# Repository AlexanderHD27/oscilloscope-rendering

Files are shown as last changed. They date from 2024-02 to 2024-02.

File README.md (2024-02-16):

# Oscilloscope Drawing

A device that draws on an oscilloscope.

## Introduction
Drawing on analog oscilloscope is almost a classic in the electronics/microcontroller community now.
This is done by setting the scope to XY-Mode and then controlling the X/Y-deflection of the electron-beam. My Scope has no Z-Channel. I cannot control the intensity of beam (or switches off) by voltage yet

This Project is my shot at this. I use custom hardware (build on perf-board) to archive this goal. I have build
a 2-Channel 16bit DAC with an refresh rate of around 1 MSample per second. Further more a usb-interface + driver shall be developed.

<p float="left">
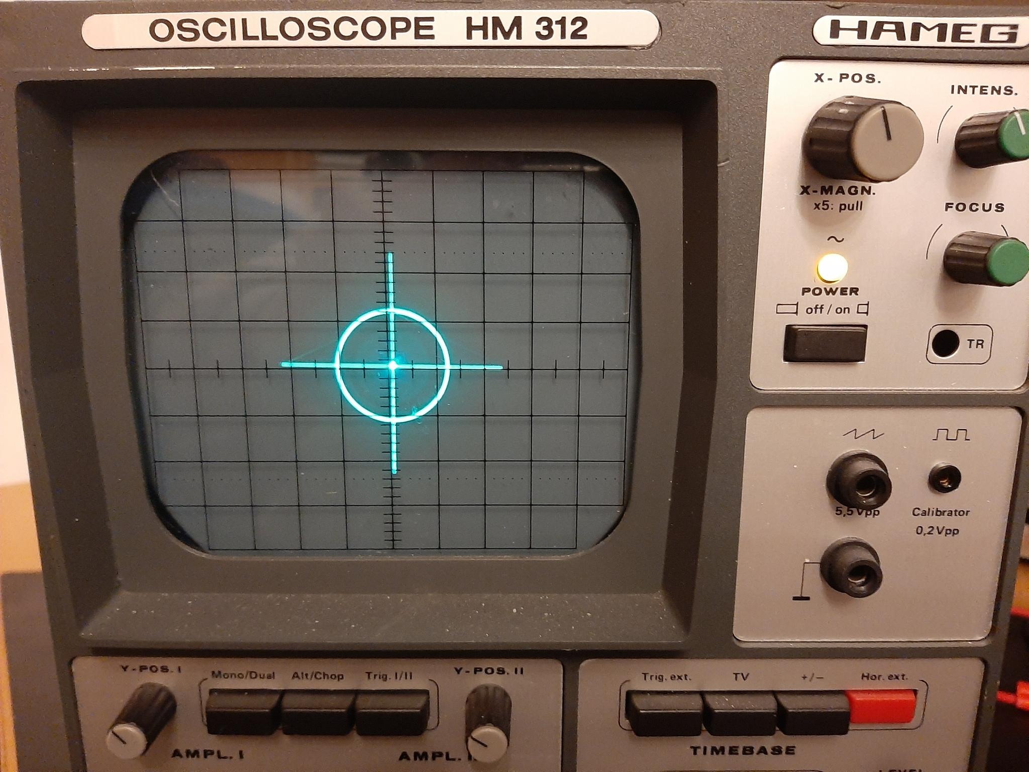
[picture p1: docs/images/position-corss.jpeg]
  
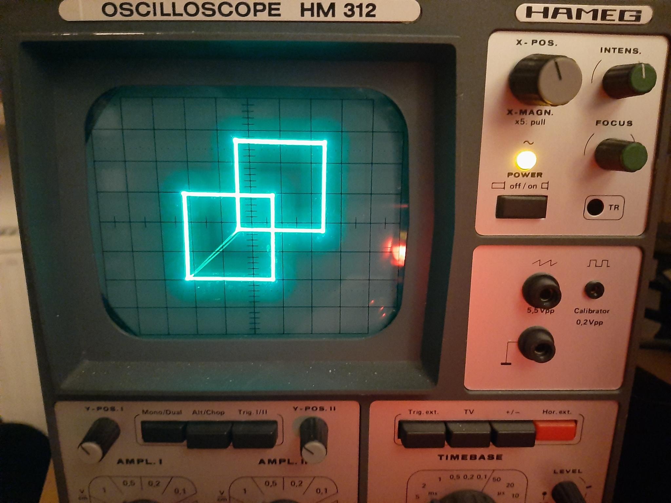
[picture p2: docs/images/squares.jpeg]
  
  
</p>

My current todo list can be found [here](TODO.md)

### Hardware

Everything is solder onto pref-boards an connected via pin-headers and jumpers

<p float="left">
  
  
</p>



(Diagram of the System-Hardware components)

The DACs are R-2R-Ladder DAC on a made custom PCB. The Input-Bits are feed from Octal-D-Latches ([74HC573](https://www.reichelt.de/oktal-d-type-latch-3-state-2--6-v-dil-20-74hc-573-p3264.html?search=74HC573)) in combination with some other logic ICs to reduce pin usage on the RPi Pico. Data sent via a 8-bit a parallel Bus to

<br>

At 1 MHz Square Wave, the analog output signal quality is significantly degraded. Testing revealed that probably R-2R_Ladder DAC is the weak link and needs further improvement. I currently use R = 11kOhm.

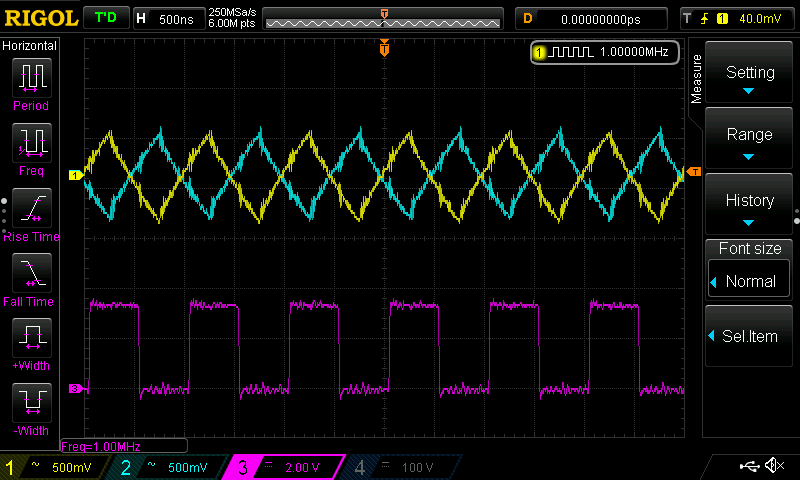
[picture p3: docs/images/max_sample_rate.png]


Yellow: X-Channel, Blue: Y-Channel, Magenta: Digital Input Signal to the DAC. (Yellow and Blue are coupled to AC, they usually to remove the 2.5V offset)

For testing the optics I did use a Hameg MH 312 Oscilloscope (I got this one used from Kleinanzeigen, so its already falling apart: semi-broken Coupling-switch, not being able focus the beam correctly, X-Pos nob falling off all the time)

### Further Components
- [Firmware](./firmware/README.md): Documentation is done by [doxygen](https://www.mintcalc.com/projects/osci-rendering/docs/index.html)

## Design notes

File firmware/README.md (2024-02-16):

Firmware for the RPi Pico for Oscilloscope Renderer

## Downloads
[main.elf](https://www.mintcalc.com/projects/osci-rendering/bin/main.elf)

## Introduction
The Firmware handles data and pushes it to the DACs resulting in a signal for the oscilloscope to be display on.

The RPi Pico is connected via USB to a host machine which provide the image. The Pico can run in two modes: Raw (Signal Data is generated on the host and just passed through) amd Instruction (The Pico recv instructions to generated the signal on the fly and the outputs it)

I'm using an RP2040 on a [Raspberry Pico](https://www.raspberrypi.com/products/raspberry-pi-pico/). Code is written in C/C++ with the [PicoSDK](https://www.raspberrypi.com/documentation/pico-sdk/)with [FreeRTOS](https://www.freertos.org/).
One of the [rp2040](https://www.raspberrypi.com/documentation/microcontrollers/rp2040.html)'s PIO cores is used in combination with a DMA-Channel to archive higher data rate.

Documentation is provided via doxygen and can be found [here](https://www.mintcalc.com/projects/osci-rendering/docs/index.html)

## Development Environment.
This Project is developed with VSCode

### Setup
The VSCode project comes pre-configured is self contained (FreeRTOS, PicoSDK).
But the appropriate tools like gcc, gdb and openocd need to be installed.
You could also use docker to build the project

#### Docker
For this you only need docker to be installed

Building the container
```sh
docker build -t rpi_pico_build ./firmware/docker
```

Running the docs: firmware
```sh
docker run -v "./":/data --rm rpi_pico_build "/data/firmware/docker/build_docs.sh"
```

Running the build: firmware
```sh
docker run -v "./":/data --rm rpi_pico_build "/data/firmware/docker/build_firmware.sh"
```

#### Installing the Build tools
```sh
sudo apt install build-essential cmake gcc-arm-none-eabi gdb-multiarch
```
(install command for ubuntu or debian based distributions)

(I once had an issue with debug in gdb-multiarch, which seems to gone now. But if you have any problems it helps building gdb-multiarch from sources. I'm using v12.2)

#### Installing OpenOCD
You also need to install `openocd` which is done by compiling from sources:
```sh
git clone https://github.com/raspberrypi/openocd.git
cd openocd 
./bootstrap 
./configure --enable-picoprobe
make -j4
sudo make install
```

For Syntax-highlight and debugging you need to load the `rpiPico-code-profile`.

Debugging and Programming is done via a SWD, I used a [Raspberry Pi Debug Probe](https://www.raspberrypi.com/products/debug-probe/) to do so. 
But a [Pico Probe](https://datasheets.raspberrypi.com/pico/getting-started-with-pico.pdf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) 
or any other SWD-Debugger should work to. You just need to edit the `firmware/scripts/launch_openocd.sh` to fit your debugger.

### Usage
Building is done with the `CMake: build main` VSCode-task

Flashing can be USB: Just press the BOOTSEL Button on the Pico and connect the RPi-Pico via USB. It should now show up as a USB-drive. 
You can now move the .uf2 file form the firmware/build/bin folder. The Pico should now restart and run the uploaded binary.

OR

Flashing can be one via SWD (recommended). You need to connect your Debugger to debug pins of the Pico (see [pinout](https://www.raspberrypi.com/documentation/microcontrollers/debug-probe.html#the-debug-probe)). Then you need to start openocd via the `Pico: launch openocd` VSCode-Task. The Pico can now be flashed with the `Pico: flash main`-Task (This task automatically builds
everything before flashing)

## Data/Buffer Flow
The Data/Buffer Flow is concert how buffer move with the RP2040, 
without the need of dynamic allocation. The Flow is based FreeRTOS's Queues.

Diagram of Data Flow

There are two type of buffers: 
- `frameBuffer_t`: These hold samples that are sent to DACs
- `instructionBuffer_t`: These hold instruction that are used to generate a signal

All buffers are preallocated and are only passed around by pointer, because they are to large (around 8kB in case of the frame_buffer) to be copied. `frameBuffer_t`/`instructionBuffer_t` struct only holds information of about the size and a pointer to the frame/instruction buffer.

The Systems main buffer-cycles:

### 1. instructionBuffer_t Cycle (in Blue)

The IO-handler (e.g USB or UART handler) requests a `instructionBuffer_t` via `dac_acquireInstructionBufferPointer()` from the `g_unusedInstructionBufferQueue` and submits the fill `instructionBuffer_t` via `dac_submitInstructions()` to the `g_instructionBufferQueue`. 

The `gen_processingTaskFunction()` takes one `instructionBuffer_t`r (if available) and generates the output signal with this. The now used `instructionBuffer_t` is submitted to `g_unusedInstructionBufferQueue` for the IO-handler to be picket up and filled again

The Structure/Format of a instruction is documented [here](../docs/Instructions.md)

### 2. frameBuffer_t Cycle (in Yellow)

The `gen_processingTaskFunction()` (aka the Signal Generator) request one unused `frameBuffer_t` from the `g_unusedFrameBufferQueue`. The Signal Generator now fills this `frameBuffer_t` with the signal generated by the instruction it got. This fill buffer is then submitted to the `g_frameBufferQueue`.

The `isrDma()` Interrupt services routine is trigger on completion of the transfer of data to the PIO sm. On Trigger, the next_buf is submitted to the DMA, an stored as the current `frameBuffer_t`. The now old `frameBuffer_t` is then pushed to the `g_unusedFrameBufferQueue`, which is then refilled by the `gen_processingTaskFunction()` again.
Then the `isrDma()` pulls one `frameBuffer_t` from the `g_frameBufferQueue`.

This is not done on every cycle but on every `FRAME_REPEAT`nth cycle (can be configured in the [dacConfig.h](./firmware/src/dac/dacConfig.h)). There for every `frameBuffer_t` is repeated `FRAME_REPEAT`-times. This is done, to have a less flickery-image on the output-oscilloscope.

In Case of an empty `g_frameBufferQueue` the current frame is repeated (after the `FRAME_REPEAT`) until one new frame becomes available.

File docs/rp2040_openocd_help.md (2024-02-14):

```
adapter
      adapter command group (command valid any time)
  adapter assert |deassert [srst|trst [assert|deassert srst|trst]]
        Controls SRST and TRST lines.
  adapter deassert |assert [srst|trst [deassert|assert srst|trst]]
        Controls SRST and TRST lines.
  adapter driver driver_name
        Select a debug adapter driver (configuration command)
  adapter list
        List all built-in debug adapter drivers (command valid any time)
  adapter name
        Returns the name of the currently selected adapter (driver)
        (command valid any time)
  adapter speed [khz]
        With an argument, change to the specified maximum jtag speed.  For
        JTAG, 0 KHz signifies adaptive clocking. With or without argument,
        display current setting. (command valid any time)
  adapter srst
        srst adapter command group (command valid any time)
    adapter srst delay [milliseconds]
          delay after deasserting SRST in ms (command valid any time)
    adapter srst pulse_width [milliseconds]
          SRST assertion pulse width in ms (command valid any time)
  adapter transports transport ... 
        Declare transports the adapter supports. (configuration command)
  adapter usb
        usb adapter command group (command valid any time)
    adapter usb location [<bus>-port[.port]...]
          display or set the USB bus location of the USB device
          (configuration command)
add_help_text command_name helptext_string
      Add new command help text; Command can be multiple tokens. (command
      valid any time)
add_script_search_dir <directory>
      dir to search for config files and scripts (command valid any time)
add_usage_text command_name usage_string
      Add new command usage text; command can be multiple tokens. (command
      valid any time)
arm
      ARM command group (command valid any time)
  arm core_state ['arm'|'thumb']
        display/change ARM core state
  arm disassemble address [count ['thumb']]
        disassemble instructions 
  arm mcr cpnum op1 CRn CRm op2 value
        write coprocessor register
  arm mrc cpnum op1 CRn CRm op2
        read coprocessor register
  arm reg
        display ARM core registers
  arm semihosting ['enable'|'disable']
        activate support for semihosting operations
  arm semihosting_cmdline arguments
        command line arguments to be passed to program
  arm semihosting_fileio ['enable'|'disable']
        activate support for semihosting fileio operations
  arm semihosting_resexit ['enable'|'disable']
        activate support for semihosting resumable exit
array2mem arrayname bitwidth address count
      convert a TCL array to memory locations and write the 8/16/32 bit
      values
bindto [name]
      Specify address by name on which to listen for incoming TCP/IP
      connections (configuration command)
bp [<address> [<asid>] <length> ['hw'|'hw_ctx']]
      list or set hardware or software breakpoint
capture command
      Capture progress output and return as tcl return value. If the
      progress output was empty, return tcl return value. (command valid
      any time)
cmsis-dap <cmd>
      perform CMSIS-DAP management (command valid any time)
  cmsis-dap cmd
        issue cmsis-dap command
  cmsis-dap info
        show cmsis-dap info
cmsis_dap_backend (auto | usb_bulk | hid)
      set the communication backend to use (USB bulk or HID).
      (configuration command)
cmsis_dap_serial serial_string
      set the serial number of the adapter (configuration command)
cmsis_dap_usb <cmd>
      USB bulk backend-specific commands (command valid any time)
  cmsis_dap_usb interface <interface_number>
        set the USB interface number to use (for USB bulk backend only)
        (configuration command)
cmsis_dap_vid_pid (vid pid)* 
      the vendor ID and product ID of the CMSIS-DAP device (configuration
      command)
command
      core command group (introspection) (command valid any time)
  command mode [command_name ...]
        Returns the command modes allowed by a command: 'any', 'config', or
        'exec'. If no command is specified, returns the current command
        mode. Returns 'unknown' if an unknown command is given. Command can
        be multiple tokens. (command valid any time)
cortex_m
      Cortex-M command group
  cortex_m maskisr ['auto'|'on'|'off'|'steponly']
        mask cortex_m interrupts
  cortex_m reset_config ['sysresetreq'|'vectreset']
        configure software reset handling (command valid any time)
  cortex_m smp [on|off]
        smp handling
  cortex_m smp_gdb
        display/fix current core played to gdb
  cortex_m smp_off
        Stop smp handling
  cortex_m smp_on
        Restart smp handling
  cortex_m vector_catch ['all'|'none'|('bus_err'|'chk_err'|...)*]
        configure hardware vectors to trigger debug entry
cti
      CTI commands (configuration command)
  cti create name '-chain-position' name [options ...]
        Creates a new CTI object (command valid any time)
  cti names
        Lists all registered CTI objects by name (command valid any time)
dap
      DAP commands (configuration command)
  dap create name '-chain-position' name
        Creates a new DAP instance (command valid any time)
  dap info [ap_num]
        display ROM table for MEM-AP of current target (default currently
        selected AP)
  dap init
        Initialize all registered DAP instances (command valid any time)
  dap names
        Lists all registered DAP instances by name (command valid any time)
debug_level number
      Sets the verbosity level of debugging output. 0 shows errors only; 1
      adds warnings; 2 (default) adds other info; 3 adds debugging; 4 adds
      extra verbose debugging. (command valid any time)
dump_image filename address size
echo [-n] string
      Logs a message at "user" priority. Output message to stdout. Option
      "-n" suppresses trailing newline (command valid any time)
exit
      exit telnet session
fast_load
      loads active fast load image to current target - mainly for profiling
      purposes
fast_load_image filename address ['bin'|'ihex'|'elf'|'s19'] [min_address [max_length]]
      Load image into server memory for later use by fast_load; primarily
      for profiling (command valid any time)
find <file>
      print full path to file according to OpenOCD search rules (command
      valid any time)
flash
      NOR flash command group (command valid any time)
  flash bank bank_id driver_name base_address size_bytes chip_width_bytes
            bus_width_bytes target [driver_options ...]
        Define a new bank with the given name, using the specified NOR
        flash driver. (configuration command)
  flash banks
        Display table with information about flash banks. (command valid
        any time)
  flash erase_address ['pad'] ['unlock'] address length
        Erase flash sectors starting at address and continuing for length
        bytes.  If 'pad' is specified, data outside that range may also be
        erased: the start address may be decreased, and length increased,
        so that all of the first and last sectors are erased. If 'unlock'
        is specified, then the flash is unprotected before erasing.
  flash erase_check bank_id
        Check erase state of all blocks in a flash bank.
  flash erase_sector bank_id first_sector_num (last_sector_num|'last')
        Erase a range of sectors in a flash bank.
  flash fillb address value n
        Fill n bytes with 8-bit value, starting at word address.  (No
        autoerase.)
  flash filld address value n
        Fill n double-words with 64-bit value, starting at word address. 
        (No autoerase.)
  flash fillh address value n
        Fill n halfwords with 16-bit value, starting at word address.  (No
        autoerase.)
  flash fillw address value n
        Fill n words with 32-bit value, starting at word address.  (No
        autoerase.)
  flash info bank_id ['sectors']
        Print information about a flash bank.
  flash init
        Initialize flash devices. (configuration command)
  flash list
        Returns a list of details about the flash banks. (command valid any
        time)
  flash mdb address [count]
        Display bytes from flash.
  flash mdh address [count]
        Display half-words from flash.
  flash mdw address [count]
        Display words from flash.
  flash padded_value bank_id value
        Set default flash padded value
  flash probe bank_id
        Identify a flash bank.
  flash protect bank_id first_block [last_block|'last'] ('on'|'off')
        Turn protection on or off for a range of protection blocks or
        sectors in a given flash bank. See 'flash info' output for a list
        of blocks.
  flash read_bank bank_id filename [offset [length]]
        Read binary data from flash bank to file. Allow optional offset
        from beginning of the bank (defaults to zero).
  flash verify_bank bank_id filename [offset]
        Compare the contents of a file with the contents of the flash bank.
        Allow optional offset from beginning of the bank (defaults to
        zero).
  flash verify_image filename [offset [file_type]]
        Verify an image against flash. Allow optional offset from beginning
        of bank (defaults to zero)
  flash write_bank bank_id filename [offset]
        Write binary data from file to flash bank. Allow optional offset
        from beginning of the bank (defaults to zero).
  flash write_image [erase] [unlock] filename [offset [file_type]]
        Write an image to flash.  Optionally first unprotect and/or erase
        the region to be used. Allow optional offset from beginning of bank
        (defaults to zero)
gdb_breakpoint_override ('hard'|'soft'|'disable')
      Display or specify type of breakpoint to be used by gdb 'break'
      commands. (command valid any time)
gdb_flash_program ('enable'|'disable')
      enable or disable flash program (configuration command)
gdb_memory_map ('enable'|'disable')
      enable or disable memory map (configuration command)
gdb_port [port_num]
      Normally gdb listens to a TCP/IP port. Each subsequent GDB server
      listens for the next port number after the base port number
      specified. No arguments reports GDB port. "pipe" means listen to
      stdin output to stdout, an integer is base port number, "disabled"
      disables port. Any other string is are interpreted as named pipe to
      listen to. Output pipe is the same name as input pipe, but with 'o'
      appended. (configuration command)
gdb_report_data_abort ('enable'|'disable')
      enable or disable reporting data aborts (configuration command)
gdb_report_register_access_error ('enable'|'disable')
      enable or disable reporting register access errors (configuration
      command)
gdb_save_tdesc
      Save the target description file
gdb_sync
      next stepi will return immediately allowing GDB to fetch register
      state without affecting target state (command valid any time)
gdb_target_description ('enable'|'disable')
      enable or disable target description (configuration command)
halt [milliseconds]
      request target to halt, then wait up to the specified number of
      milliseconds (default 5000) for it to complete
help [command_name]
      Show full command help; command can be multiple tokens. (command
      valid any time)
init
      Initializes configured targets and servers.  Changes command mode
      from CONFIG to EXEC.  Unless 'noinit' is called, this command is
      called automatically at the end of startup. (command valid any time)
itm
      itm command group (command valid any time)
  itm port <port> (0|1|on|off)
        Enable or disable ITM stimulus port (command valid any time)
  itm ports (0|1|on|off)
        Enable or disable all ITM stimulus ports (command valid any time)
jsp_port [port_num]
      Specify port on which to listen for incoming JSP telnet connections.
      (command valid any time)
load_image filename address ['bin'|'ihex'|'elf'|'s19'] [min_address] [max_length]
log_output [file_name | "default"]
      redirect logging to a file (default: stderr) (command valid any time)
mdb ['phys'] address [count]
      display memory bytes
mdd ['phys'] address [count]
      display memory double-words
mdh ['phys'] address [count]
      display memory half-words
mdw ['phys'] address [count]
      display memory words
measure_clk
      Runs a test to measure the JTAG clk. Useful with RCLK / RTCK.
      (command valid any time)
mem2array arrayname bitwidth address count
      read 8/16/32 bit memory and return as a TCL array for script
      processing
mmw address setbits clearbits
      Modify word in memory. new_val = (old_val & ~clearbits) | setbits;
      (command valid any time)
mrb address
      Returns value of byte in memory. (command valid any time)
mrh address
      Returns value of halfword in memory. (command valid any time)
mrw address
      Returns value of word in memory. (command valid any time)
ms
      Returns ever increasing milliseconds. Used to calculate differences
      in time. (command valid any time)
mwb ['phys'] address value [count]
      write memory byte
mwd ['phys'] address value [count]
      write memory double-word
mwh ['phys'] address value [count]
      write memory half-word
mww ['phys'] address value [count]
      write memory word
nand
      NAND flash command group (command valid any time)
  nand device bank_id driver target [driver_options ...]
        defines a new NAND bank (configuration command)
  nand drivers
        lists available NAND drivers (command valid any time)
  nand init
        initialize NAND devices (configuration command)
noinit
      Prevent 'init' from being called at startup. (configuration command)
ocd_find file
      find full path to file (command valid any time)
pld
      programmable logic device commands (command valid any time)
  pld device driver_name [driver_args ... ]
        configure a PLD device (configuration command)
  pld init
        initialize PLD devices (configuration command)
poll ['on'|'off']
      poll target state; or reconfigure background polling
poll_period
      set the servers polling period (command valid any time)
power_restore
      Overridable procedure run when power restore is detected. Runs 'reset
      init' by default. (command valid any time)
profile seconds filename [start end]
      profiling samples the CPU PC
program <filename> [address] [pre-verify] [verify] [reset] [exit]
      write an image to flash, address is only required for binary images.
      verify, reset, exit are optional (command valid any time)
ps  
      list all tasks 
rbp 'all' | address
      remove breakpoint
reg [(register_number|register_name) [(value|'force')]]
      display (reread from target with "force") or set a register; with no
      arguments, displays all registers and their values
reset [run|halt|init]
      Reset all targets into the specified mode. Default reset mode is run,
      if not given.
reset_config [none|trst_only|srst_only|trst_and_srst]
          [srst_pulls_trst|trst_pulls_srst|combined|separate]
          [srst_gates_jtag|srst_nogate] [trst_push_pull|trst_open_drain]
          [srst_push_pull|srst_open_drain]
          [connect_deassert_srst|connect_assert_srst]
      configure adapter reset behavior (command valid any time)
reset_nag ['enable'|'disable']
      Nag after each reset about options that could have been enabled to
      improve performance.  (command valid any time)
resume [address]
      resume target execution from current PC or address
rp2040.core0
      target command group (command valid any time)
  rp2040.core0 arm
        ARM command group (command valid any time)
    rp2040.core0 arm core_state ['arm'|'thumb']
          display/change ARM core state
    rp2040.core0 arm disassemble address [count ['thumb']]
          disassemble instructions 
    rp2040.core0 arm mcr cpnum op1 CRn CRm op2 value
          write coprocessor register
    rp2040.core0 arm mrc cpnum op1 CRn CRm op2
          read coprocessor register
    rp2040.core0 arm reg
          display ARM core registers
    rp2040.core0 arm semihosting ['enable'|'disable']
          activate support for semihosting operations
    rp2040.core0 arm semihosting_cmdline arguments
          command line arguments to be passed to program
    rp2040.core0 arm semihosting_fileio ['enable'|'disable']
          activate support for semihosting fileio operations
    rp2040.core0 arm semihosting_resexit ['enable'|'disable']
          activate support for semihosting resumable exit
  rp2040.core0 arp_examine ['allow-defer']
        used internally for reset processing
  rp2040.core0 arp_halt
        used internally for reset processing
  rp2040.core0 arp_halt_gdb
        used internally for reset processing to halt GDB
  rp2040.core0 arp_poll
        used internally for reset processing
  rp2040.core0 arp_reset
        used internally for reset processing
  rp2040.core0 arp_waitstate
        used internally for reset processing
  rp2040.core0 array2mem arrayname bitwidth address count
        Writes Tcl array of 8/16/32 bit numbers to target memory
  rp2040.core0 cget target_attribute
        returns the specified target attribute (command valid any time)
  rp2040.core0 configure [target_attribute ...]
        configure a new target for use (command valid any time)
  rp2040.core0 cortex_m
        Cortex-M command group
    rp2040.core0 cortex_m maskisr ['auto'|'on'|'off'|'steponly']
          mask cortex_m interrupts
    rp2040.core0 cortex_m reset_config ['sysresetreq'|'vectreset']
          configure software reset handling (command valid any time)
    rp2040.core0 cortex_m smp [on|off]
          smp handling
    rp2040.core0 cortex_m smp_gdb
          display/fix current core played to gdb
    rp2040.core0 cortex_m smp_off
          Stop smp handling
    rp2040.core0 cortex_m smp_on
          Restart smp handling
    rp2040.core0 cortex_m vector_catch ['all'|'none'|('bus_err'|'chk_err'|...)*]
          configure hardware vectors to trigger debug entry
  rp2040.core0 curstate
        displays the current state of this target
  rp2040.core0 eventlist
        displays a table of events defined for this target
  rp2040.core0 examine_deferred
        used internally for reset processing
  rp2040.core0 invoke-event event_name
        invoke handler for specified event
  rp2040.core0 itm
        itm command group (command valid any time)
    rp2040.core0 itm port <port> (0|1|on|off)
          Enable or disable ITM stimulus port (command valid any time)
    rp2040.core0 itm ports (0|1|on|off)
          Enable or disable all ITM stimulus ports (command valid any time)
  rp2040.core0 mdb address [count]
        Display target memory as 8-bit bytes
  rp2040.core0 mdd address [count]
        Display target memory as 64-bit words
  rp2040.core0 mdh address [count]
        Display target memory as 16-bit half-words
  rp2040.core0 mdw address [count]
        Display target memory as 32-bit words
  rp2040.core0 mem2array arrayname bitwidth address count
        Loads Tcl array of 8/16/32 bit numbers from target memory
  rp2040.core0 mwb address data [count]
        Write byte(s) to target memory
  rp2040.core0 mwd address data [count]
        Write 64-bit word(s) to target memory
  rp2040.core0 mwh address data [count]
        Write 16-bit half-word(s) to target memory
  rp2040.core0 mww address data [count]
        Write 32-bit word(s) to target memory
  rp2040.core0 rtt
        RTT target commands
    rp2040.core0 rtt channellist
          list available channels
    rp2040.core0 rtt channels
          list available channels
    rp2040.core0 rtt polling_interval [interval]
          show or set polling interval in ms
    rp2040.core0 rtt setup <address> <size> <ID>
          setup RTT (command valid any time)
    rp2040.core0 rtt start
          start RTT
    rp2040.core0 rtt stop
          stop RTT
  rp2040.core0 tpiu
        tpiu command group (command valid any time)
    rp2040.core0 tpiu config (disable | ((external | internal (<filename> | <:port> | -)) (sync <port
              width> | ((manchester | uart) <formatter enable>))
              <TRACECLKIN freq> [<trace freq>]))
          Configure TPIU features (command valid any time)
  rp2040.core0 was_examined
        used internally for reset processing
rp2040.core0.dap
      dap instance command group (command valid any time)
  rp2040.core0.dap apcsw [value [mask]]
        Set CSW default bits (command valid any time)
  rp2040.core0.dap apid [ap_num]
        return ID register from AP (default currently selected AP)
  rp2040.core0.dap apreg ap_num reg [value]
        read/write a register from AP (reg is byte address of a word
        register, like 0 4 8...)
  rp2040.core0.dap apsel [ap_num]
        Set the currently selected AP (default 0) and display the result
        (command valid any time)
  rp2040.core0.dap baseaddr [ap_num]
        return debug base address from MEM-AP (default currently selected
        AP)
  rp2040.core0.dap dpreg reg [value]
        read/write a register from DP (reg is byte address (bank << 4 |
        reg) of a word register, like 0 4 8...)
  rp2040.core0.dap info [ap_num]
        display ROM table for MEM-AP (default currently selected AP)
  rp2040.core0.dap memaccess [cycles]
        set/get number of extra tck for MEM-AP memory bus access [0-255]
  rp2040.core0.dap ti_be_32_quirks [enable]
        set/get quirks mode for TI TMS450/TMS570 processors (configuration
        command)
rp2040.core1
      target command group (command valid any time)
  rp2040.core1 arm
        ARM command group (command valid any time)
    rp2040.core1 arm core_state ['arm'|'thumb']
          display/change ARM core state
    rp2040.core1 arm disassemble address [count ['thumb']]
          disassemble instructions 
    rp2040.core1 arm mcr cpnum op1 CRn CRm op2 value
          write coprocessor register
    rp2040.core1 arm mrc cpnum op1 CRn CRm op2
          read coprocessor register
    rp2040.core1 arm reg
          display ARM core registers
    rp2040.core1 arm semihosting ['enable'|'disable']
          activate support for semihosting operations
    rp2040.core1 arm semihosting_cmdline arguments
          command line arguments to be passed to program
    rp2040.core1 arm semihosting_fileio ['enable'|'disable']
          activate support for semihosting fileio operations
    rp2040.core1 arm semihosting_resexit ['enable'|'disable']
          activate support for semihosting resumable exit
  rp2040.core1 arp_examine ['allow-defer']
        used internally for reset processing
  rp2040.core1 arp_halt
        used internally for reset processing
  rp2040.core1 arp_halt_gdb
        used internally for reset processing to halt GDB
  rp2040.core1 arp_poll
        used internally for reset processing
  rp2040.core1 arp_reset
        used internally for reset processing
  rp2040.core1 arp_waitstate
        used internally for reset processing
  rp2040.core1 array2mem arrayname bitwidth address count
        Writes Tcl array of 8/16/32 bit numbers to target memory
  rp2040.core1 cget target_attribute
        returns the specified target attribute (command valid any time)
  rp2040.core1 configure [target_attribute ...]
        configure a new target for use (command valid any time)
  rp2040.core1 cortex_m
        Cortex-M command group
    rp2040.core1 cortex_m maskisr ['auto'|'on'|'off'|'steponly']
          mask cortex_m interrupts
    rp2040.core1 cortex_m reset_config ['sysresetreq'|'vectreset']
          configure software reset handling (command valid any time)
    rp2040.core1 cortex_m smp [on|off]
          smp handling
    rp2040.core1 cortex_m smp_gdb
          display/fix current core played to gdb
    rp2040.core1 cortex_m smp_off
          Stop smp handling
    rp2040.core1 cortex_m smp_on
          Restart smp handling
    rp2040.core1 cortex_m vector_catch ['all'|'none'|('bus_err'|'chk_err'|...)*]
          configure hardware vectors to trigger debug entry
  rp2040.core1 curstate
        displays the current state of this target
  rp2040.core1 eventlist
        displays a table of events defined for this target
  rp2040.core1 examine_deferred
        used internally for reset processing
  rp2040.core1 invoke-event event_name
        invoke handler for specified event
  rp2040.core1 itm
        itm command group (command valid any time)
    rp2040.core1 itm port <port> (0|1|on|off)
          Enable or disable ITM stimulus port (command valid any time)
    rp2040.core1 itm ports (0|1|on|off)
          Enable or disable all ITM stimulus ports (command valid any time)
  rp2040.core1 mdb address [count]
        Display target memory as 8-bit bytes
  rp2040.core1 mdd address [count]
        Display target memory as 64-bit words
  rp2040.core1 mdh address [count]
        Display target memory as 16-bit half-words
  rp2040.core1 mdw address [count]
        Display target memory as 32-bit words
  rp2040.core1 mem2array arrayname bitwidth address count
        Loads Tcl array of 8/16/32 bit numbers from target memory
  rp2040.core1 mwb address data [count]
        Write byte(s) to target memory
  rp2040.core1 mwd address data [count]
        Write 64-bit word(s) to target memory
  rp2040.core1 mwh address data [count]
        Write 16-bit half-word(s) to target memory
  rp2040.core1 mww address data [count]
        Write 32-bit word(s) to target memory
  rp2040.core1 rtt
        RTT target commands
    rp2040.core1 rtt channellist
          list available channels
    rp2040.core1 rtt channels
          list available channels
    rp2040.core1 rtt polling_interval [interval]
          show or set polling interval in ms
    rp2040.core1 rtt setup <address> <size> <ID>
          setup RTT (command valid any time)
    rp2040.core1 rtt start
          start RTT
    rp2040.core1 rtt stop
          stop RTT
  rp2040.core1 tpiu
        tpiu command group (command valid any time)
    rp2040.core1 tpiu config (disable | ((external | internal (<filename> | <:port> | -)) (sync <port
              width> | ((manchester | uart) <formatter enable>))
              <TRACECLKIN freq> [<trace freq>]))
          Configure TPIU features (command valid any time)
  rp2040.core1 was_examined
        used internally for reset processing
rp2040.core1.dap
      dap instance command group (command valid any time)
  rp2040.core1.dap apcsw [value [mask]]
        Set CSW default bits (command valid any time)
  rp2040.core1.dap apid [ap_num]
        return ID register from AP (default currently selected AP)
  rp2040.core1.dap apreg ap_num reg [value]
        read/write a register from AP (reg is byte address of a word
        register, like 0 4 8...)
  rp2040.core1.dap apsel [ap_num]
        Set the currently selected AP (default 0) and display the result
        (command valid any time)
  rp2040.core1.dap baseaddr [ap_num]
        return debug base address from MEM-AP (default currently selected
        AP)
  rp2040.core1.dap dpreg reg [value]
        read/write a register from DP (reg is byte address (bank << 4 |
        reg) of a word register, like 0 4 8...)
  rp2040.core1.dap info [ap_num]
        display ROM table for MEM-AP (default currently selected AP)
  rp2040.core1.dap memaccess [cycles]
        set/get number of extra tck for MEM-AP memory bus access [0-255]
  rp2040.core1.dap ti_be_32_quirks [enable]
        set/get quirks mode for TI TMS450/TMS570 processors (configuration
        command)
rtt
      RTT (command valid any time)
  rtt channellist
        list available channels
  rtt channels
        list available channels
  rtt polling_interval [interval]
        show or set polling interval in ms
  rtt server
        RTT server (command valid any time)
    rtt server start <port> <channel>
          Start a RTT server (command valid any time)
    rtt server stop <port>
          Stop a RTT server (command valid any time)
  rtt setup <address> <size> <ID>
        setup RTT (command valid any time)
  rtt start
        start RTT
  rtt stop
        stop RTT
rwp address
      remove watchpoint
script <file>
      filename of OpenOCD script (tcl) to run (command valid any time)
shutdown
      shut the server down (command valid any time)
sleep milliseconds ['busy']
      Sleep for specified number of milliseconds.  "busy" will busy wait
      instead (avoid this). (command valid any time)
soft_reset_halt
      halt the target and do a soft reset
srst_deasserted
      Overridable procedure run when srst deassert is detected. Runs 'reset
      init' by default. (command valid any time)
step [address]
      step one instruction from current PC or address
swd
      SWD command group (command valid any time)
  swd newdap
        declare a new SWD DAP (configuration command)
target
      configure target (configuration command)
  target create name type '-chain-position' name [options ...]
        Creates and selects a new target (configuration command)
  target current
        Returns the currently selected target (command valid any time)
  target init
        initialize targets (configuration command)
  target names
        Returns the names of all targets as a list of strings (command
        valid any time)
  target smp targetname1 targetname2 ...
        gather several target in a smp list (command valid any time)
  target types
        Returns the available target types as a list of strings (command
        valid any time)
target_request
      target request command group (command valid any time)
  target_request debugmsgs ['enable'|'charmsg'|'disable']
        display and/or modify reception of debug messages from target
targets [target]
      change current default target (one parameter) or prints table of all
      targets (no parameters) (command valid any time)
tcl_notifications [on|off]
      Target Notification output
tcl_port [port_num]
      Specify port on which to listen for incoming Tcl syntax.  Read help
      on 'gdb_port'. (configuration command)
tcl_trace [on|off]
      Target trace output
telnet_port [port_num]
      Specify port on which to listen for incoming telnet connections. 
      Read help on 'gdb_port'. (configuration command)
test_image filename [offset [type]]
test_mem_access size
      Test the target's memory access functions
tpiu
      tpiu command group (command valid any time)
  tpiu config (disable | ((external | internal (<filename> | <:port> | -)) (sync <port
            width> | ((manchester | uart) <formatter enable>)) <TRACECLKIN
            freq> [<trace freq>]))
        Configure TPIU features (command valid any time)
trace
      trace command group
  trace history ['clear'|size]
        display trace history, clear history or set size
  trace point ['clear'|address]
        display trace points, clear list of trace points, or add new
        tracepoint at address
transport
      Transport command group (command valid any time)
  transport init
        Initialize this session's transport (command valid any time)
  transport list
        list all built-in transports (command valid any time)
  transport select [transport_name]
        Select this session's transport (command valid any time)
usage [command_name]
      Show basic command usage; command can be multiple tokens. (command
      valid any time)
verify_image filename [offset [type]]
verify_image_checksum filename [offset [type]]
version
      show program version (command valid any time)
virt2phys virtual_address
      translate a virtual address into a physical address (command valid
      any time)
wait_halt [milliseconds]
      wait up to the specified number of milliseconds (default 5000) for a
      previously requested halt
wp [address length [('r'|'w'|'a') value [mask]]]
      list (no params) or create watchpoints
```

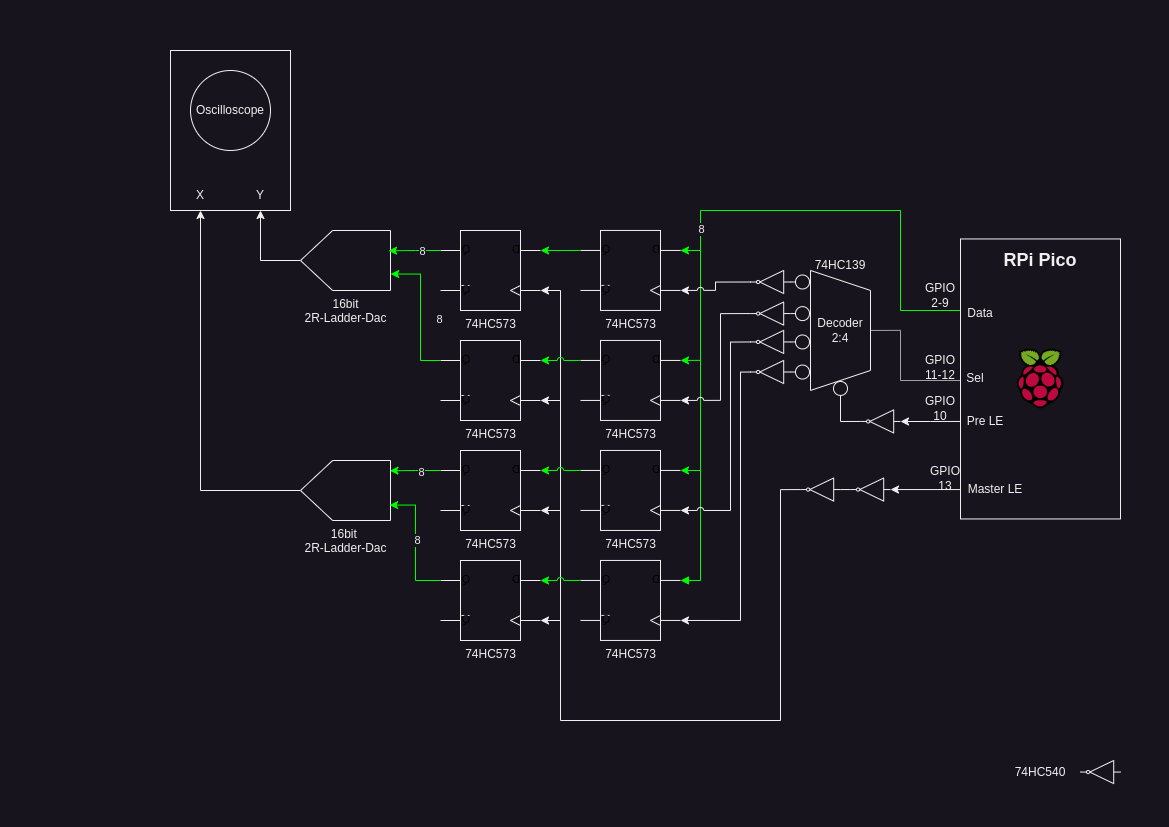
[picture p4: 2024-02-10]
docs/drawio/HardwareSystemDiagram/HardwareSystemDiagram.png

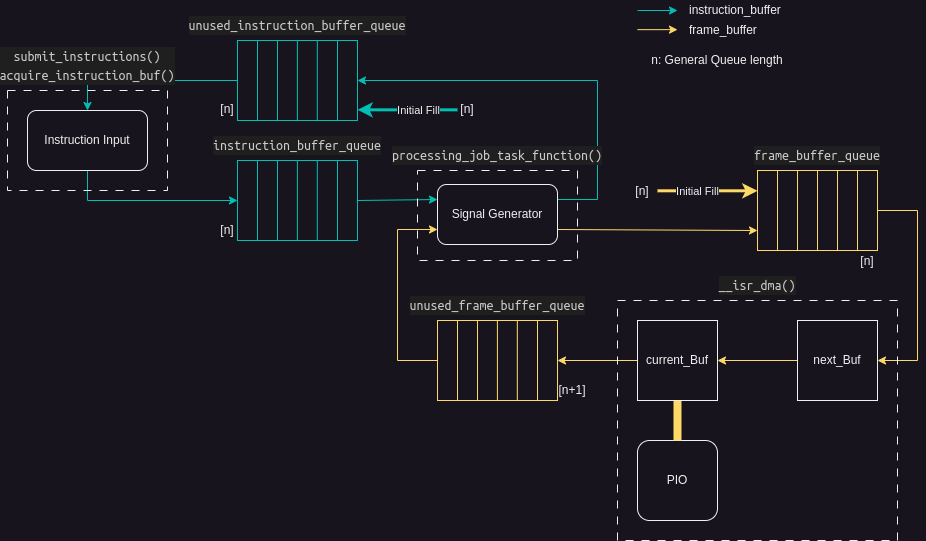
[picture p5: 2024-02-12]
docs/drawio/DataFlow_RP2040/DataFlow_RP2040.drawio.png

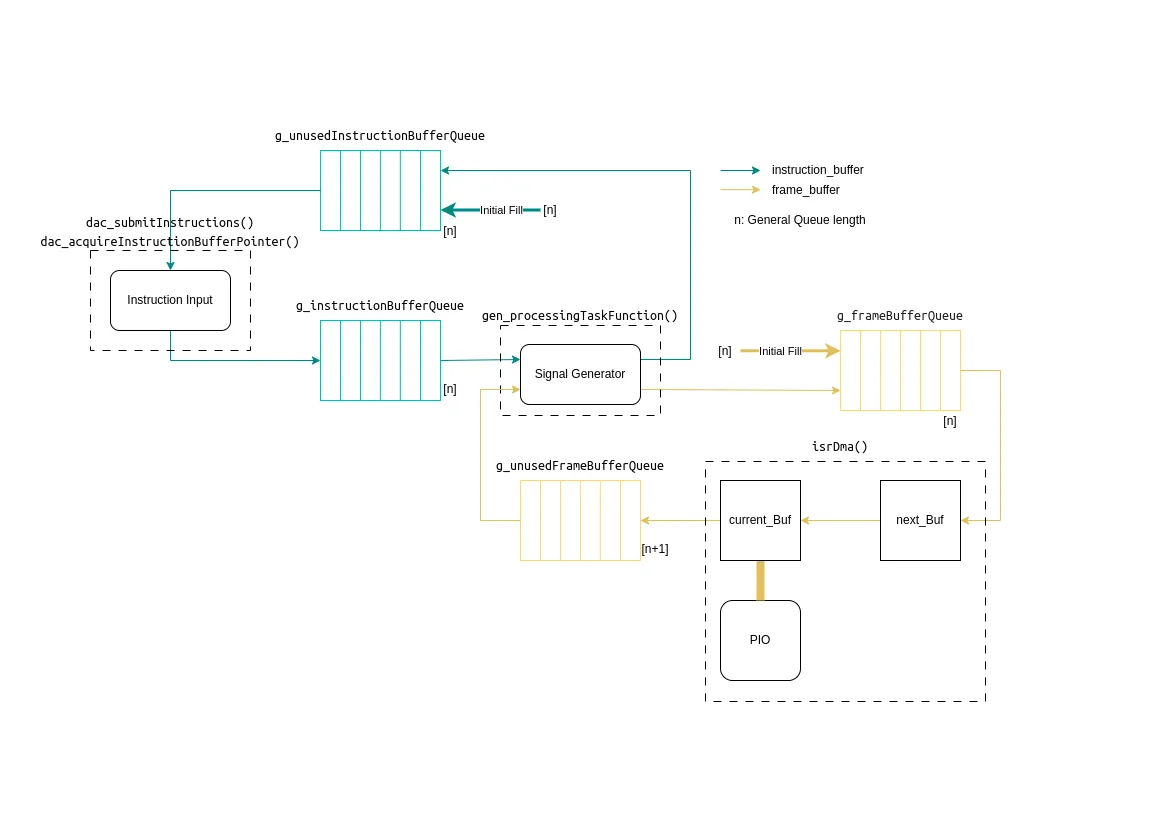
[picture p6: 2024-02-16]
docs/drawio/DataFlow_RP2040/DataFlow_RP2040.drawio.webp

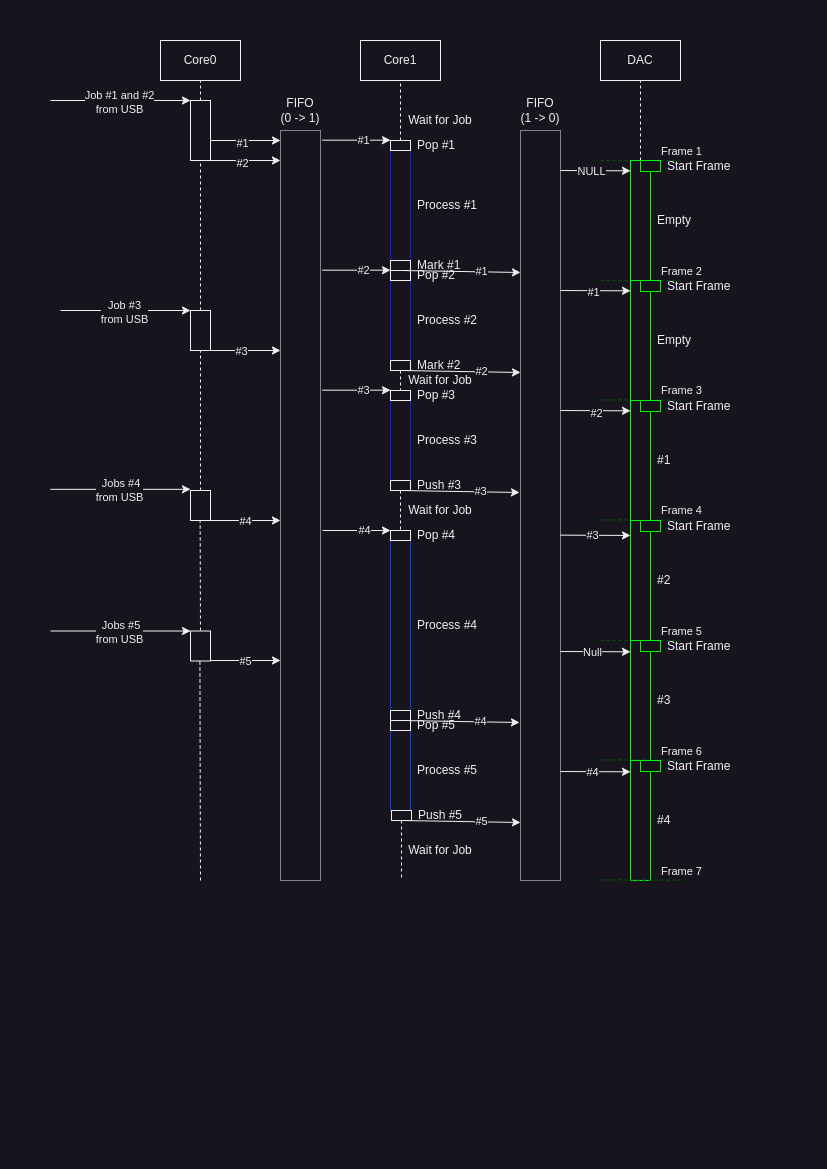
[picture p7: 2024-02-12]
docs/drawio/DEBRICATED_FlowChart-JobMangement/DEBRICATED_FlowChart-JobMangement.drawio.png

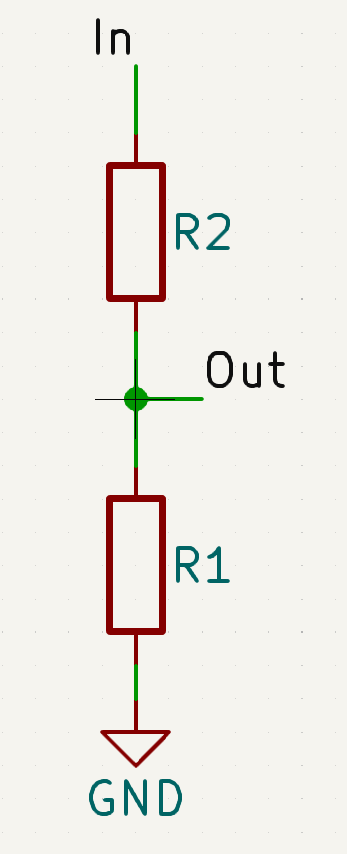
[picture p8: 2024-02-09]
tools/voltageDivider.png

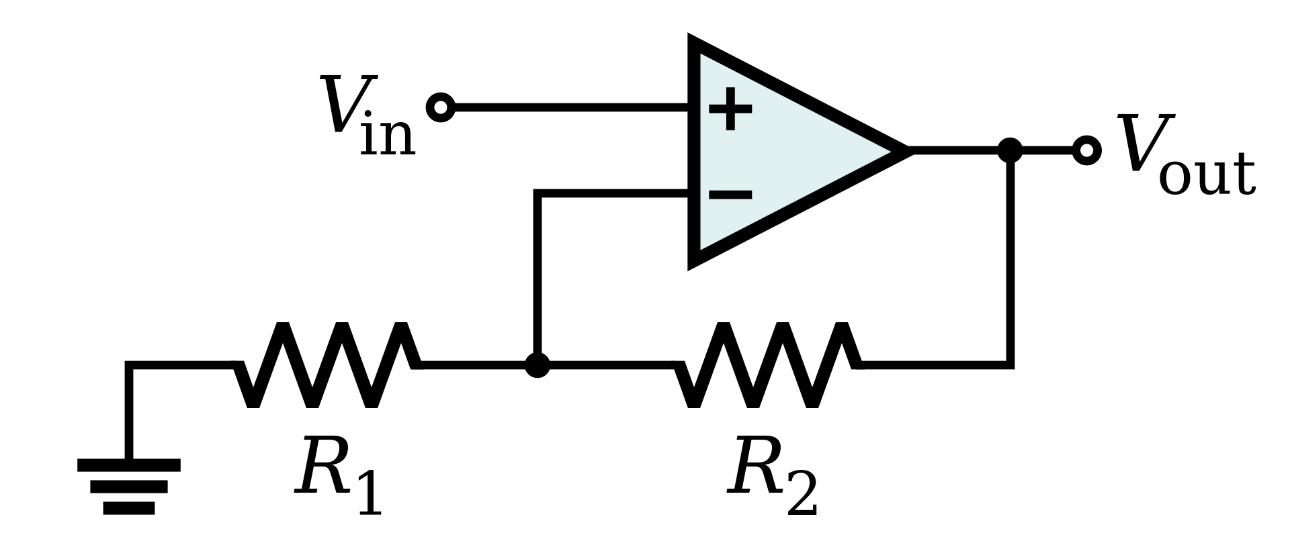
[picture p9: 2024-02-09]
tools/Op-Amp_Non-Inverting_Amplifier.svg.png

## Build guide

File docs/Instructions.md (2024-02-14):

Instruction have always the same format:

| byte-offset | Value/Meaning |
|---|---|
| 0 | Instruction ID: What to generate (see table) |
| 1-2 | Length: How many samples should be generated? |
| 3- 5n | parameter0, parameter1, ... (up to four parameter) |

The first bit of the Instruction specifies the channel (0 = X, 1 = Y), the instruction is applied to.

It's expected that every channels is completely filled (nor over oder under flowed)

### Instruction Types
| ID | Type | Parameters |
|---|---|---|
| `0x00` | NONE | - |
| `0x01` | CONST | level |
| `0x02` | LINE | fromValue, toValue |
| `0x03` | CUBIC | fromValue, toValue, CTRL |
| `0x04` | QUADRATIC | fromValue, toValue, CTRL0, CTRL1 |
| `0x05` | SINE | lowValue, highValue, freqH, freqL, phase |

(CUBIC and QUADRATIC refer to [Bézier Curves](https://en.wikipedia.org/wiki/B%C3%A9zier_curve), see [desmos](https://www.desmos.com/calculator/q5xuopyfo6))

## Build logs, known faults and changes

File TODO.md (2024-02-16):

## TODOs

- [ ] Analog Frontend
- [ ] EEPROM connection for temp storage
- [ ] Fix DAC (replace 11kOhm with 100Ohm)

- [ ] FreeRTOS Architecture
  - [X] Fix Deadlock problem with queues
  - [ ] Add Multicore Support
  - [ ] Adding switch from Job-bases system to Raw Buffer

- [ ] USB Interface
    - [ ] Raw Interface (sending raw buffers)
    - [X] Compressed Interfaces (Line, Points, Spline, Sin)

- [X] DevOps
    - [X] Setup Jenkins
    - [X] Pipeline for Building Firmware
    - [X] Pipeline for Building and Deploing docs

- [ ] Rendering 
    - [ ] 3D-Cube  
    - [ ] Terminal
    - [ ] Bad Apple?

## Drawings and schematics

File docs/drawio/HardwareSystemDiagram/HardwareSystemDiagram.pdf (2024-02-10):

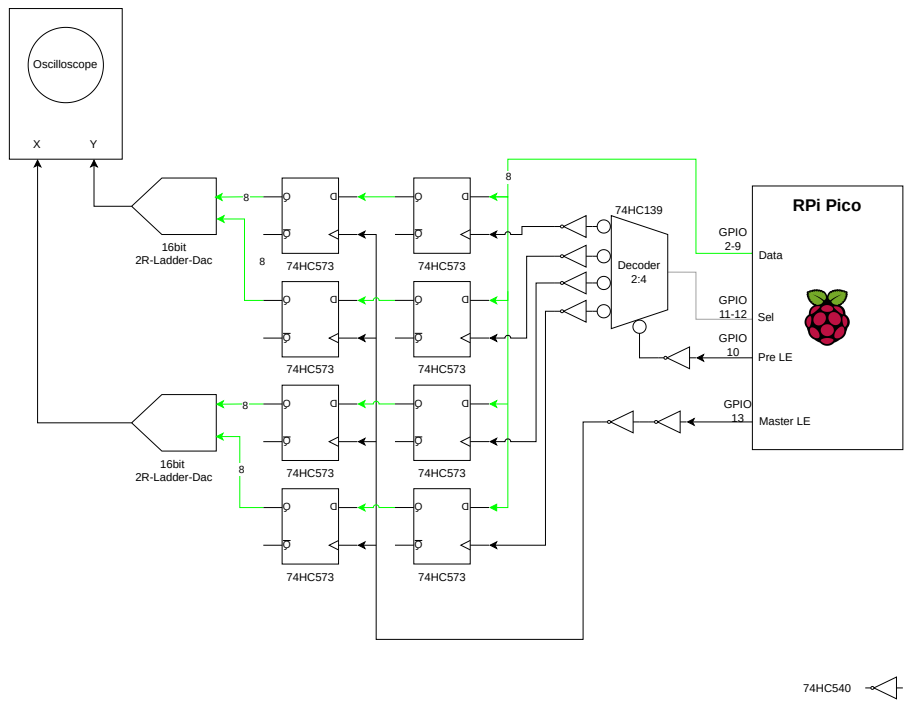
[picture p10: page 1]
Oscilloscope; 16bit 2R-Ladder-Dac; Decoder 2:4; GPIO 11-12; GPIO 2-9; GPIO; Master LE; Sel; Data; Pre LE; RPi Pico; GPIO 10

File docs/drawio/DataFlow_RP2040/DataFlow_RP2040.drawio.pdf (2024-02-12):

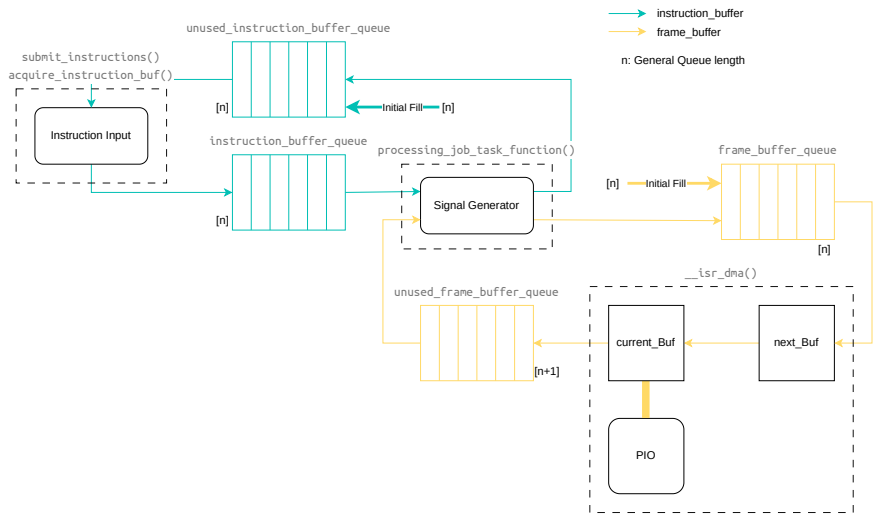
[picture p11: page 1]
Instruction Input; instruction_buffer_queue; unused_instruction_buffer_queue; Signal Generator; PIO; unused_frame_buffer_queue; frame_buffer_queue; next_Buf; __isr_dma(); current_Buf; processing_job_task_function(); Initial Fill; submit_instructions() acquire_instruction_buf(); instruction_buffer; frame_buffer

n: General Queue length

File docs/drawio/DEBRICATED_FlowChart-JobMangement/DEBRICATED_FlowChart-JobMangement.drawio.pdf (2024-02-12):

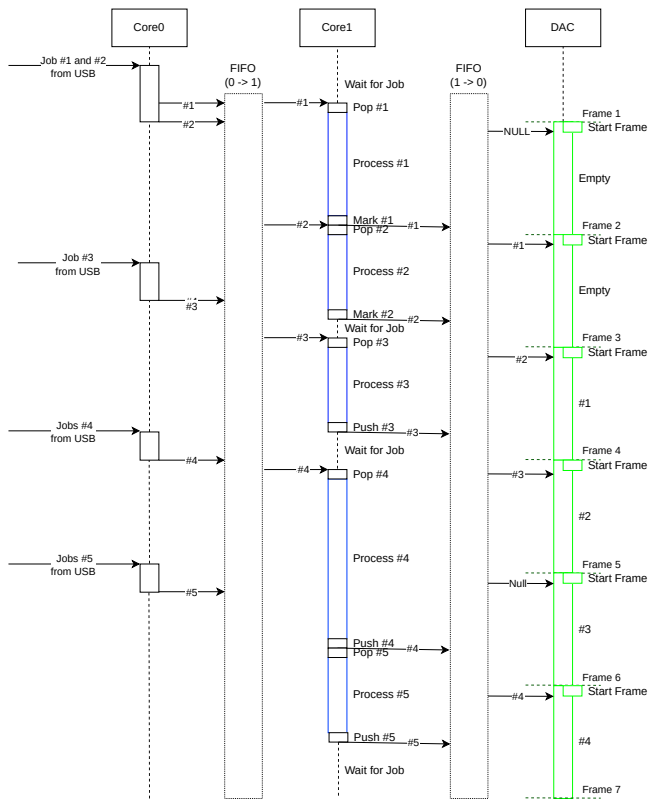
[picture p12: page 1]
Core0; Core1; Job #1 and #2 from USB; Job #3 from USB; Jobs #4 from USB; Process #1; Process #2; Process #3; DAC; Process #4; Mark #1 Pop #2; FIFO (0 -> 1); Push #4; Frame 1; Frame 2; Frame 3; Frame 4; Empty; FIFO (1 -> 0); Frame 5; NULL; Process #5; Push #5; Pop #5; Frame 6; Null; Start Frame; Frame 7; Start Frame #4; Jobs #5 from USB

Wait for Job
Pop #1

Mark #2
Pop #3

Push #3
Pop #4

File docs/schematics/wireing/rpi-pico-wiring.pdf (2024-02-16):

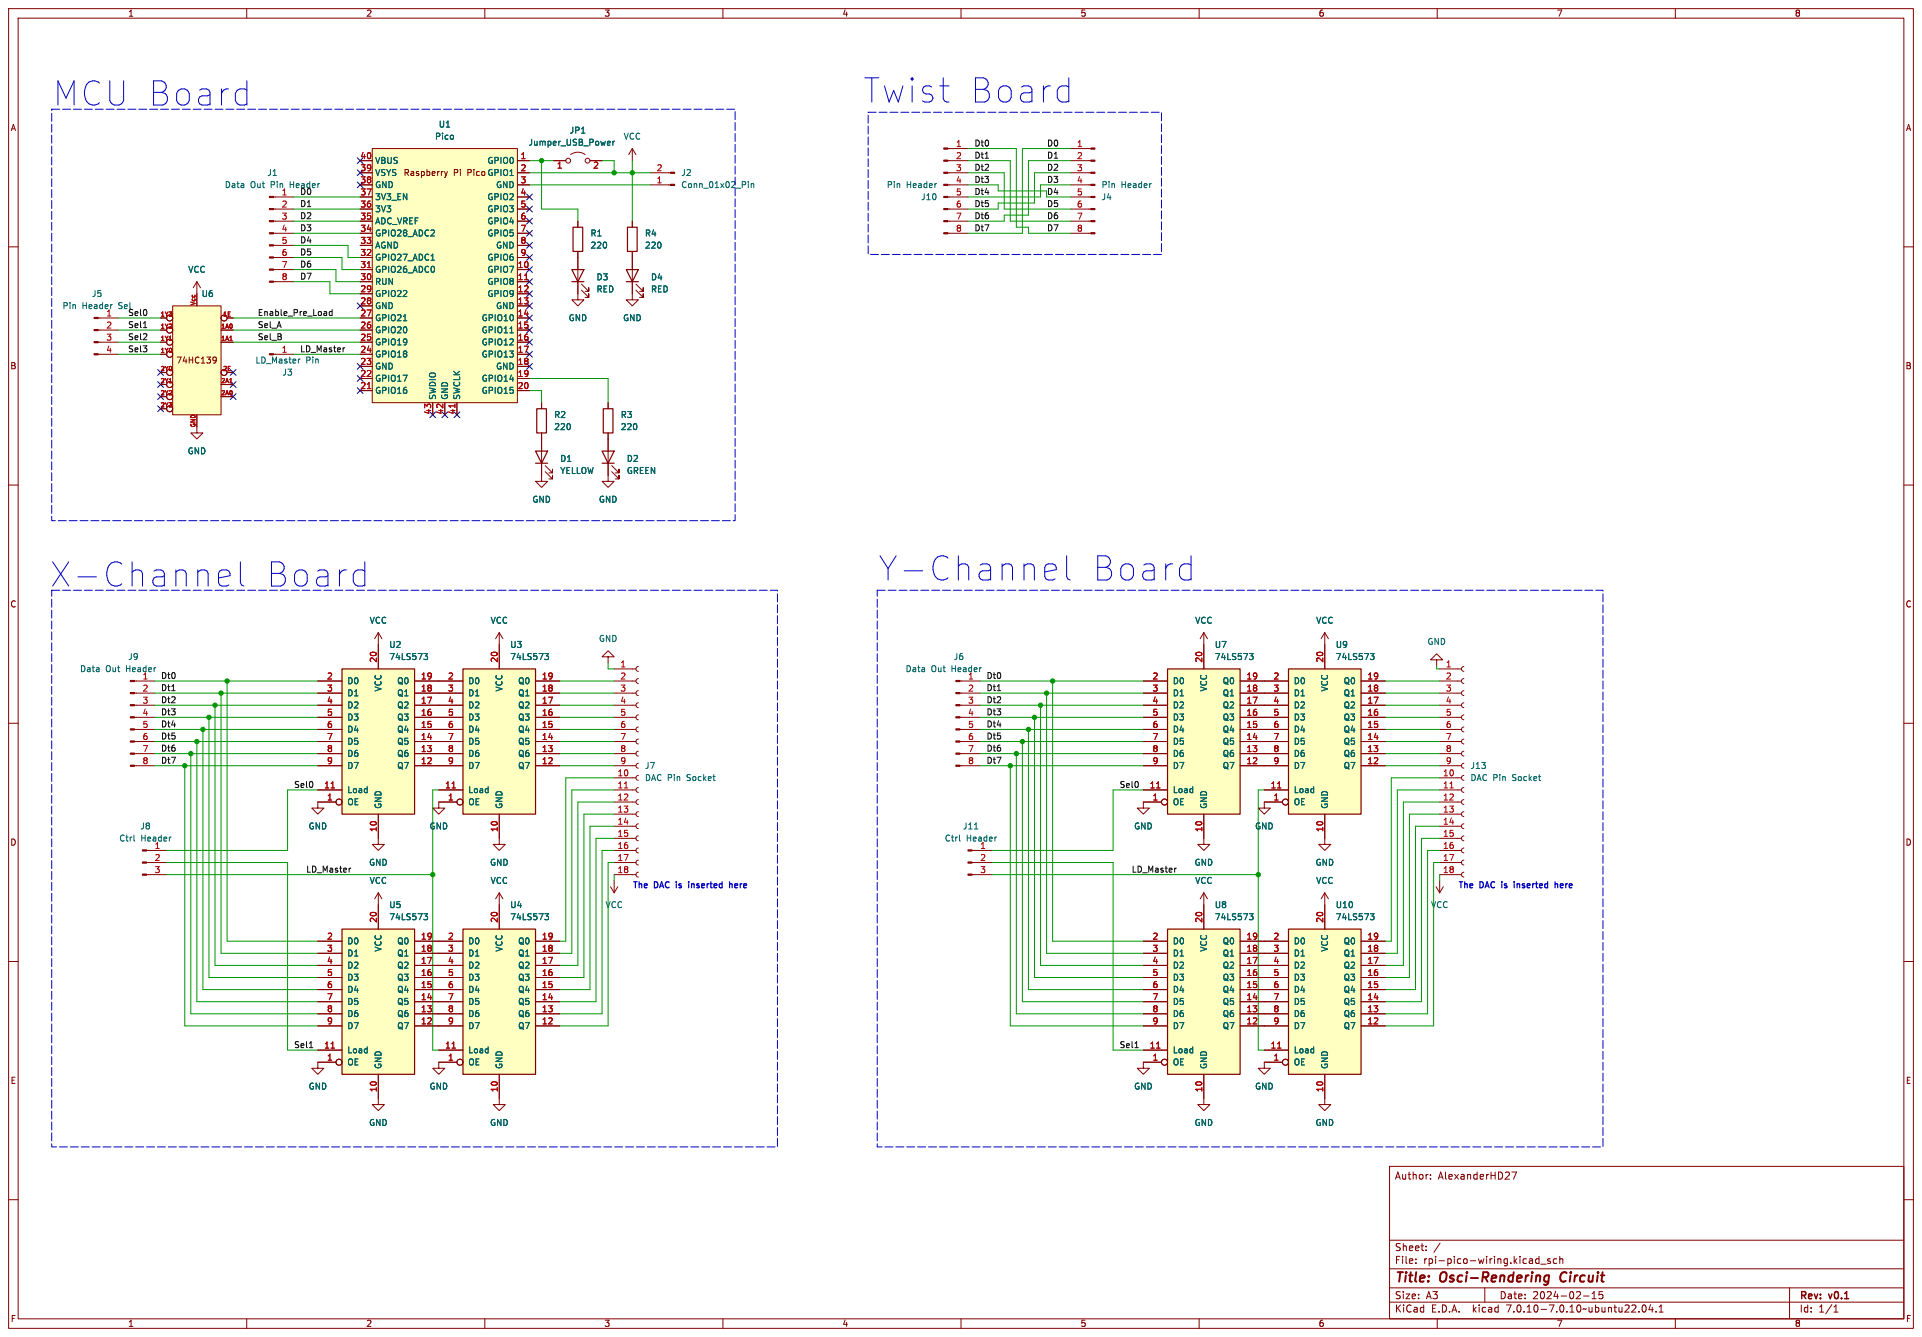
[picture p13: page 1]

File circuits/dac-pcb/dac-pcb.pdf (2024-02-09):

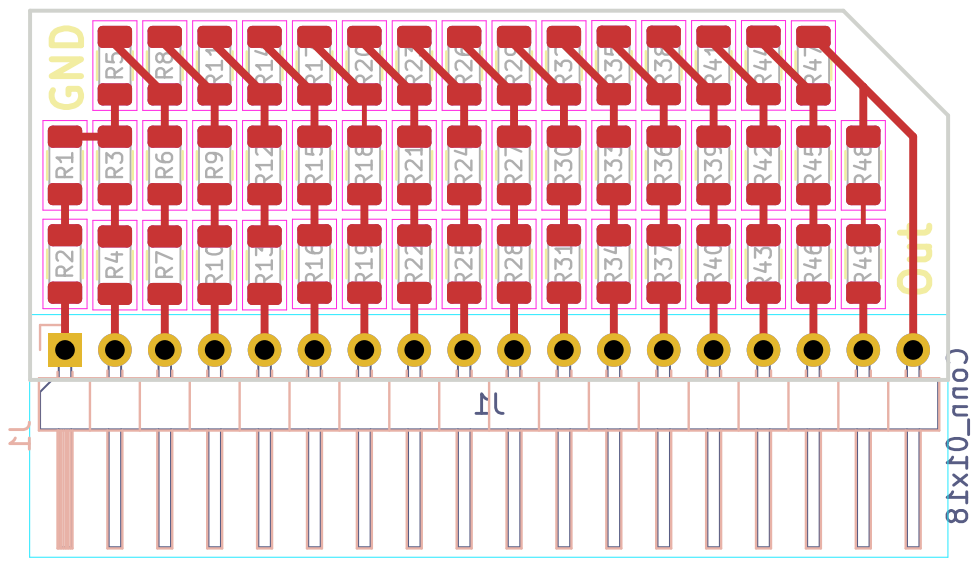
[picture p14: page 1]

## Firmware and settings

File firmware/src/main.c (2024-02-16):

/**
 * @file main.c
 * @author AlexanderHD27 (you@domain.com)
 * @brief Main file of the RPi Pico Firmware for the Oscilloscope-Renderer
 * @version 0.1
 * @date 2024-02-15
 * 
 * @copyright Copyright (c) 2024
 * 
 */

#include <stdio.h>
#include <stdlib.h>
#include <math.h>

#include "FreeRTOS.h"
#include "FreeRTOSConfig.h"
#include "task.h"

#include "hardware/pio.h"
#include "dac.h"

#define PIN_DATA_START 2
#define PIN_CTRL_START 10

// Pin Layout:
// 2-9  Parallel Data
//   10 Enable_Pre_Load
//   11 Sel_A
//   12 Sel_B
//   13 LD_Master

#define PIN_LED 25
#define PIN_LED_GREEN 17
#define PIN_LED_YELLOW 16

uint32_t counter = 0;

void provideJobTask(void * param) {
    while (true) {
        uint8_t * _insBuf = dac_acquireInstructionBufferPointer();
        uint8_t * insBuf = _insBuf;
        insBuf += gen_addInstructionSine(insBuf, X, BUFFER_SIZE/2, 0x00a0, 0xff60, (uint16_t)(BUFFER_SIZE/2/3), BUFFER_SIZE/2/4);
        insBuf += gen_addInstructionSine(insBuf, Y, BUFFER_SIZE/2, 0x00a0, 0xff60, (uint16_t)(BUFFER_SIZE/2/2), 0x0000);
        insBuf += gen_addInstructionConst(insBuf, X, BUFFER_SIZE/2, 0x7fff - 0xffff*(0.5*cosf( PI*((float)(counter*3)/(BUFFER_SIZE/2-1)))) );
        insBuf += gen_addInstructionConst(insBuf, Y, BUFFER_SIZE/2, 0x7fff - 0xffff*(0.5*sinf( PI*((float)(counter*2)/(BUFFER_SIZE/2-1)))) );
counter = (counter + 0x1f) % BUFFER_SIZE;
        dac_submitInstructions(_insBuf, insBuf - _insBuf);
    }
}


int main() {

    // Init Debug LEDs
    const uint32_t gpioOutMask = (1 << PIN_LED) | (1 << PIN_LED_GREEN) | (1 << PIN_LED_YELLOW);
    gpio_init_mask(gpioOutMask);
    gpio_set_dir_masked(gpioOutMask, gpioOutMask);
    gpio_put(16, true);

    // Claim PIO & sm
    PIO pio = pio0;
    uint sm = pio_claim_unused_sm(pio, true);

    // Init DAC
    dac_init(pio, sm, PIN_DATA_START, PIN_CTRL_START);

    // Create Test Task for providing a constant stream of instruction
    TaskHandle_t provideJobTaskHandle;
    xTaskCreate(provideJobTask, "[Test] Create Jobs", 128, NULL, 1, &provideJobTaskHandle);

    // Start FreeRTOS Scheduler
    vTaskStartScheduler();
}

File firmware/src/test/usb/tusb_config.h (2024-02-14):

/*
 * The MIT License (MIT)
 *
 * Copyright (c) 2019 Ha Thach (tinyusb.org)
 *
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
 */

#ifndef _TUSB_CONFIG_H_
#define _TUSB_CONFIG_H_

#ifdef __cplusplus
 extern "C" {
#endif

//--------------------------------------------------------------------
// COMMON CONFIGURATION
//--------------------------------------------------------------------

// defined by board.mk
#ifndef CFG_TUSB_MCU
    #error CFG_TUSB_MCU must be defined
#endif

// RHPort number used for device can be defined by board.mk, default to port 0
#ifndef BOARD_DEVICE_RHPORT_NUM
  #define BOARD_DEVICE_RHPORT_NUM     0
#endif

// RHPort max operational speed can defined by board.mk
// Default to Highspeed for MCU with internal HighSpeed PHY (can be port specific), otherwise FullSpeed
#ifndef BOARD_DEVICE_RHPORT_SPEED
  #if (CFG_TUSB_MCU == OPT_MCU_LPC18XX || CFG_TUSB_MCU == OPT_MCU_LPC43XX || CFG_TUSB_MCU == OPT_MCU_MIMXRT10XX || \
       CFG_TUSB_MCU == OPT_MCU_NUC505  || CFG_TUSB_MCU == OPT_MCU_CXD56 || CFG_TUSB_MCU == OPT_MCU_SAMX7X)
    #define BOARD_DEVICE_RHPORT_SPEED   OPT_MODE_HIGH_SPEED
  #else
    #define BOARD_DEVICE_RHPORT_SPEED   OPT_MODE_FULL_SPEED
  #endif
#endif

// Device mode with rhport and speed defined by board.mk
#if   BOARD_DEVICE_RHPORT_NUM == 0
  #define CFG_TUSB_RHPORT0_MODE     (OPT_MODE_DEVICE | BOARD_DEVICE_RHPORT_SPEED)
#elif BOARD_DEVICE_RHPORT_NUM == 1
  #define CFG_TUSB_RHPORT1_MODE     (OPT_MODE_DEVICE | BOARD_DEVICE_RHPORT_SPEED)
#else
  #error "Incorrect RHPort configuration"
#endif

#ifndef CFG_TUSB_OS
#define CFG_TUSB_OS               OPT_OS_NONE
#endif

// CFG_TUSB_DEBUG is defined by compiler in DEBUG build
// #define CFG_TUSB_DEBUG           0

/* USB DMA on some MCUs can only access a specific SRAM region with restriction on alignment.
 * Tinyusb use follows macros to declare transferring memory so that they can be put
 * into those specific section.
 * e.g
 * - CFG_TUSB_MEM SECTION : __attribute__ (( section(".usb_ram") ))
 * - CFG_TUSB_MEM_ALIGN   : __attribute__ ((aligned(4)))
 */
#ifndef CFG_TUSB_MEM_SECTION
#define CFG_TUSB_MEM_SECTION
#endif

#ifndef CFG_TUSB_MEM_ALIGN
#define CFG_TUSB_MEM_ALIGN          __attribute__ ((aligned(4)))
#endif

//--------------------------------------------------------------------
// DEVICE CONFIGURATION
//--------------------------------------------------------------------

#ifndef CFG_TUD_ENDPOINT0_SIZE
#define CFG_TUD_ENDPOINT0_SIZE    64
#endif

//------------- CLASS -------------//
#define CFG_TUD_HID               1
#define CFG_TUD_CDC               0
#define CFG_TUD_MSC               0
#define CFG_TUD_MIDI              0
#define CFG_TUD_VENDOR            0

// HID buffer size Should be sufficient to hold ID (if any) + Data
#define CFG_TUD_HID_EP_BUFSIZE    16

#ifdef __cplusplus
 }
#endif

#endif /* _TUSB_CONFIG_H_ */

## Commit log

2024-02-09 Added DAC-pcb
    [dac-pcb-B_Cu.gbl, dac-pcb-B_Mask.gbs, dac-pcb-B_Paste.gbp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]
2024-02-09 Added PCB Manfucaturer to README
2024-02-10 Update README.md with link to dac-pcb prod-file
2024-02-10 Change PICO sdk to workspace-local sdk
2024-02-10 Got Pico SDK example of USB to work
2024-02-11 Create Flow-Chart for Job System
2024-02-11 Fixed Problem with second core not starting after reset via openocd
    [main.c]
2024-02-12 Created flow-chart for new queue-based dataflow
2024-02-12 FlowChart: Updated some stuff and added task names
2024-02-12 Fixed deadlock issue by removing jobs queue and implemented frame-repeat
    [main.c]
2024-02-12 Change buffer miss to check next cycle (instead of next frame repeat cycle)
2024-02-12 Update README.md inserted missing new line
2024-02-13 Implement cubic generation for floats and fixpoint
    [main.c]
2024-02-13 Fixed bug in parameter reading
    [main.c]
2024-02-14 Implemented Fixpoint taylor series for sin
    [main.c]
2024-02-14 Fixed skipped samples by Invalid Offset
2024-02-14 Squashed commit of the following:
    commit 72b70e328290417968875a4158c1d6cbc331ddba
    Author: alexander <alexander@hal>
    Date: Wed Feb 14 22:44:02 2024 +0100
    Added Demo of rendering sine
    commit 6b187587fa563b0e1b60a151fd09fe397362b101
    Author: alexander <alexander@hal>
    Date: Wed Feb 14 22:12:42 2024 +0100
    built small sin&cos demo
    commit c6dd80fef513bc75719bafb12aa628732da98220
    Author: alexander <alexander@hal>
    Date: Wed Feb 14 20:28:16 2024 +0100
    Fixed skipped samples by Invalid Offset
    commit c5aac70cf1988cd3d6b81d99f717e4e656dbc2b9
    Author: alexander <alexander@hal>
    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
    [main.c]
2024-02-15 Added Wiring Drawing
    [rpi-pico-wiring.kicad_pcb, rpi-pico-wiring.kicad_sch]
2024-02-15 Added KiCad Lib for RPi Pico Symbol
